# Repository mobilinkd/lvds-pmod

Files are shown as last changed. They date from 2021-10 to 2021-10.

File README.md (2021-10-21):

# 2m QSD PMOD

The board is designed for experimenting with an all-digital SERDES-based
quadrature sampling detector (QSD) and quadrature modulator.

This is a PMOD for differential (balanced) to/from single-ended (unbalanced)
I/O.  It has a 4:1 balun to match the 200 Ohm impedance of the PMOD to the
50 Ohm SMA.

The center tap on the balun is biased at VDD/2.

The board includes a 4-pole band-pass filter centered around the 2m amateur
radio band.  It is a Chebyshev filter with 1dB ripple in the passband. It is
designed to both be an anti-aliasing filter and to suppress the commercial
FM radio band.

This repo contains KiCAD files and Gerbers for those wanting to make their
own boards.

An [interactive BOM](bom/ibom-2m%20QSD%20PMOD-A.html) is available.

This project is OSHW (Open Source Hardware), released under the GPLv3 license.

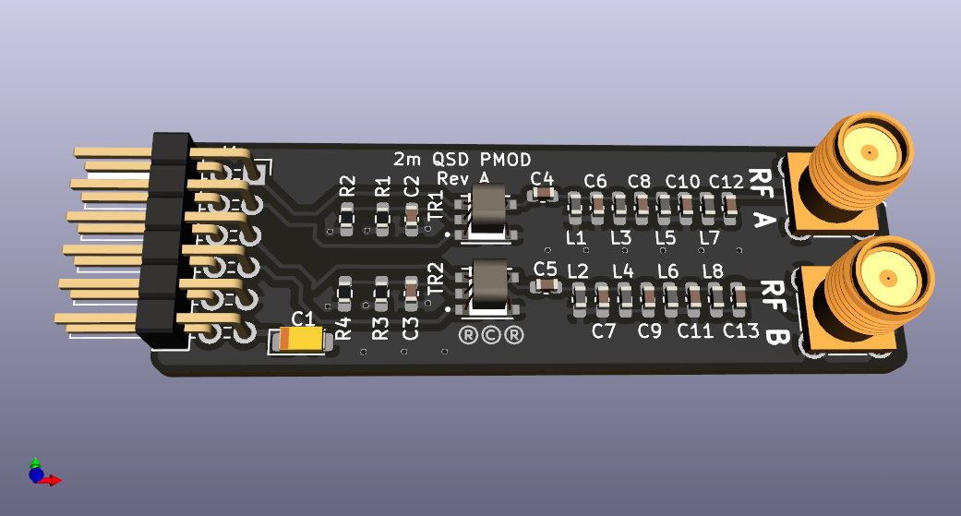
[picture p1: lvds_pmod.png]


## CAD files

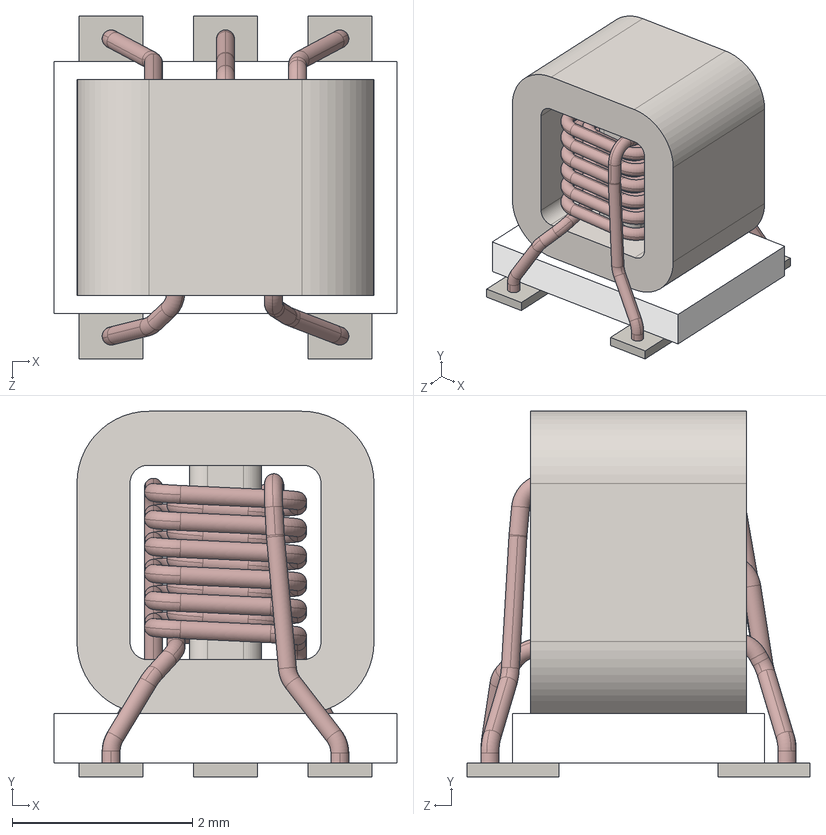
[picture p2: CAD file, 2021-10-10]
models/User Library-TC1-1T+.step
3.81 x 4.06 x 3.81 mm

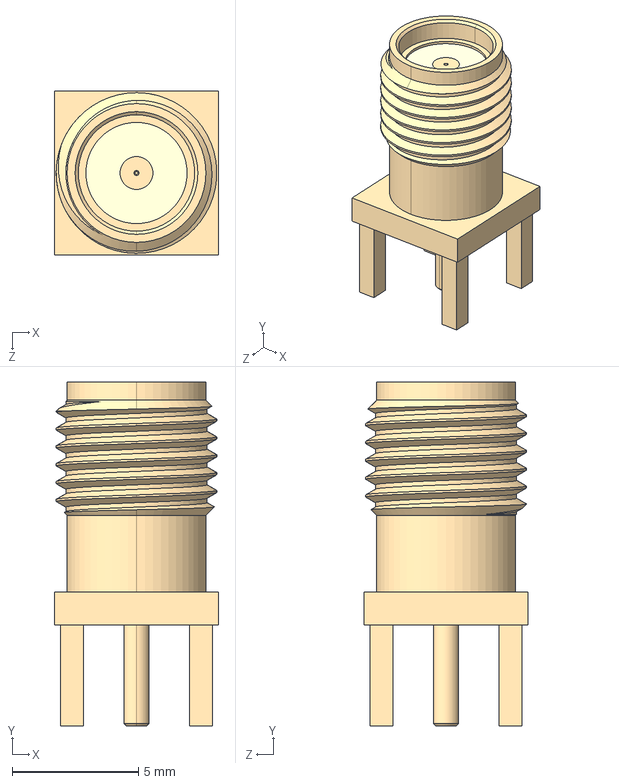
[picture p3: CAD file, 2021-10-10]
models/SMA CONNECTOR--3DModel-STEP-1.STEP
6.50 x 13.6 x 6.50 mm

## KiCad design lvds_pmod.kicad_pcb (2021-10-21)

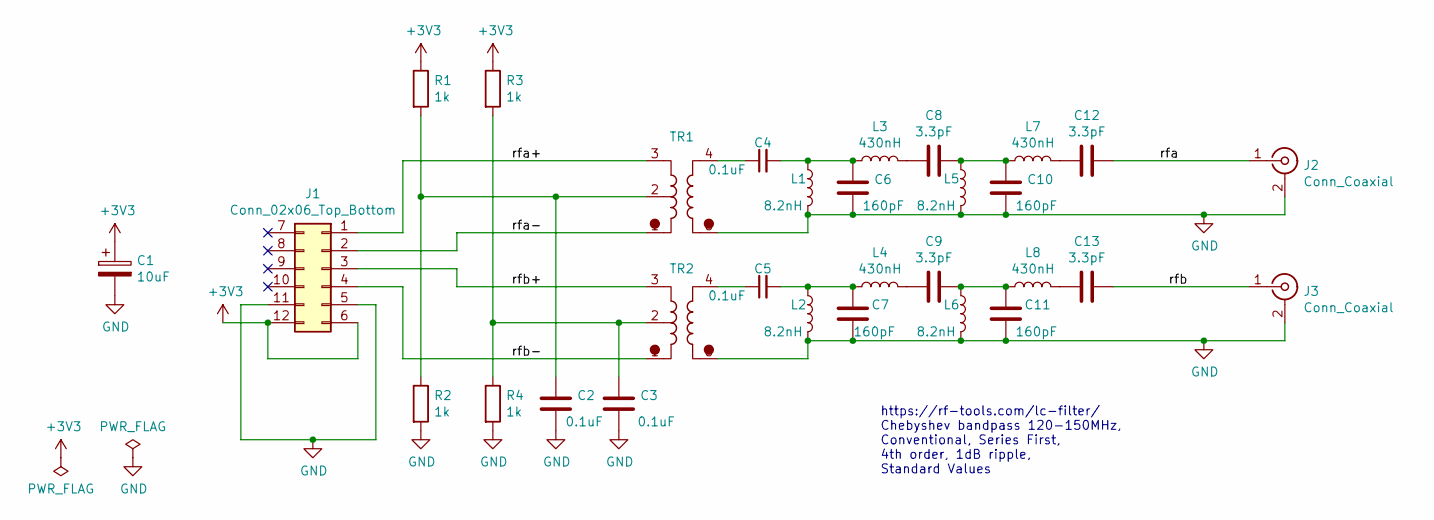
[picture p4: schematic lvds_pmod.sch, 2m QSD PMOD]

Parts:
C1: 10uF; CP_EIA-3216-12_Kemet-S_Pad1.58x1.35mm_HandSolder
C2, C3: 0.1uF; C_0603_1608Metric_Pad1.08x0.95mm_HandSolder
C4, C5: 0.1uF; C_0603_1608Metric
C6, C7, C10, C11: 160pF; C_0603_1608Metric_Pad1.08x0.95mm_HandSolder
C8, C9, C12, C13: 3.3pF; C_0603_1608Metric_Pad1.08x0.95mm_HandSolder
J1: Conn_02x06_Top_Bottom; PinHeader_2x06_P2.54mm_Horizontal
J2, J3: Conn_Coaxial; SMA_Amphenol_901-144_Vertical
L1, L2, L5, L6: 8.2nH; L_0603_1608Metric_Pad1.05x0.95mm_HandSolder
L3, L4, L7, L8: 430nH; L_0603_1608Metric_Pad1.05x0.95mm_HandSolder
R1, R2, R3, R4: 1k; R_0603_1608Metric_Pad0.98x0.95mm_HandSolder
TR1, TR2: CX2047LNL; XFMR_TC1-1-13M+

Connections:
+3V3: C1.1, J1.6, J1.12, R1.1, R3.1
/rfa: C12.1, J2.1 (In)
/rfa+: J1.1, TR1.3
/rfa-: J1.2, TR1.1
/rfb: C13.1, J3.1 (In)
/rfb+: J1.3, TR2.3
/rfb-: J1.4, TR2.1
GND: C1.2, C2.2, C3.2, C6.2, C7.2, C10.2, C11.2, J1.5, J1.11, J2.2 (Ext), J3.2 (Ext), L1.2, L2.2, L5.2, L6.2, R2.2, R4.2, TR1.6, TR2.6
unnamed: C2.1, R1.2, R2.1, TR1.2
unnamed: C3.1, R3.2, R4.1, TR2.2
unnamed: C4.1, TR1.4
unnamed: C4.2, C6.1, L1.1, L3.1
unnamed: C5.1, TR2.4
unnamed: C5.2, C7.1, L2.1, L4.1
unnamed: C8.2, L3.2
unnamed: C9.2, L4.2
unnamed: C8.1, C10.1, L5.1, L7.1
unnamed: C9.1, C11.1, L6.1, L8.1
unnamed: C12.2, L7.2
unnamed: C13.2, L8.2

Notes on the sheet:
https://rf-tools.com/lc-filter/ Chebyshev bandpass 120-150MHz, Conventional, Series First, 4th order, 1dB ripple, Standard Values

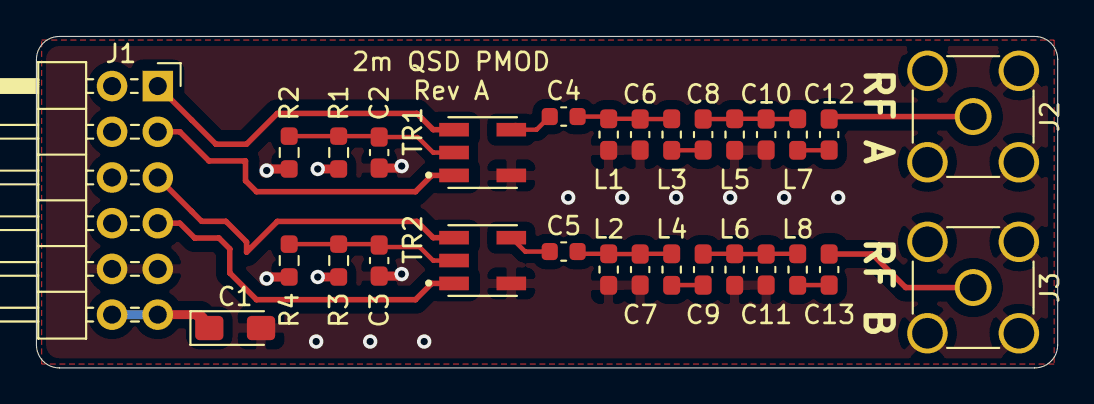
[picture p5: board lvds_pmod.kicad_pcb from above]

Board: 4 copper layers, 56.7 x 18.4 mm, 31 parts (1 on the bottom side), 20 nets.

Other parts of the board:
G1: LOGO; Mobilinkd_Logo

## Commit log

2021-10-10 Initial commit.
    [SMA CONNECTOR--3DModel-STEP-1.STEP, User Library-TC1-1T+.step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]
2021-10-21 Add interactive BOM.
    [lvds_pmod.kicad_pcb]
